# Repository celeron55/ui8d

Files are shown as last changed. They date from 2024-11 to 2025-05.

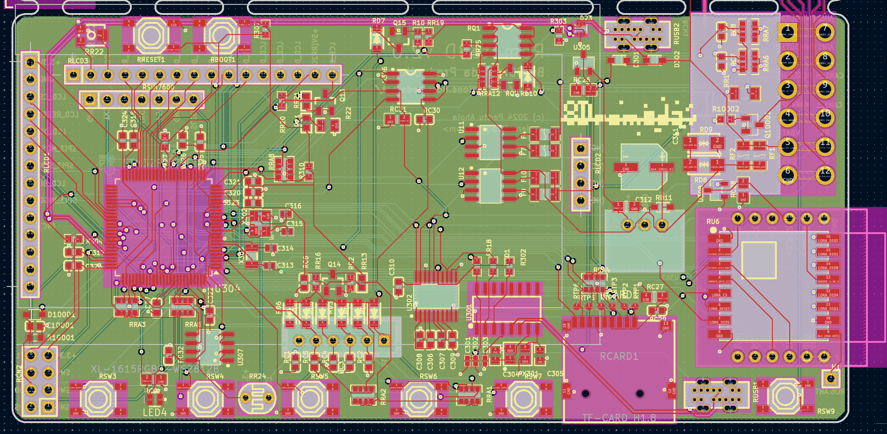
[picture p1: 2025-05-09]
ui8dhw2.0/ui8dhw2.0_pcb_layers.png

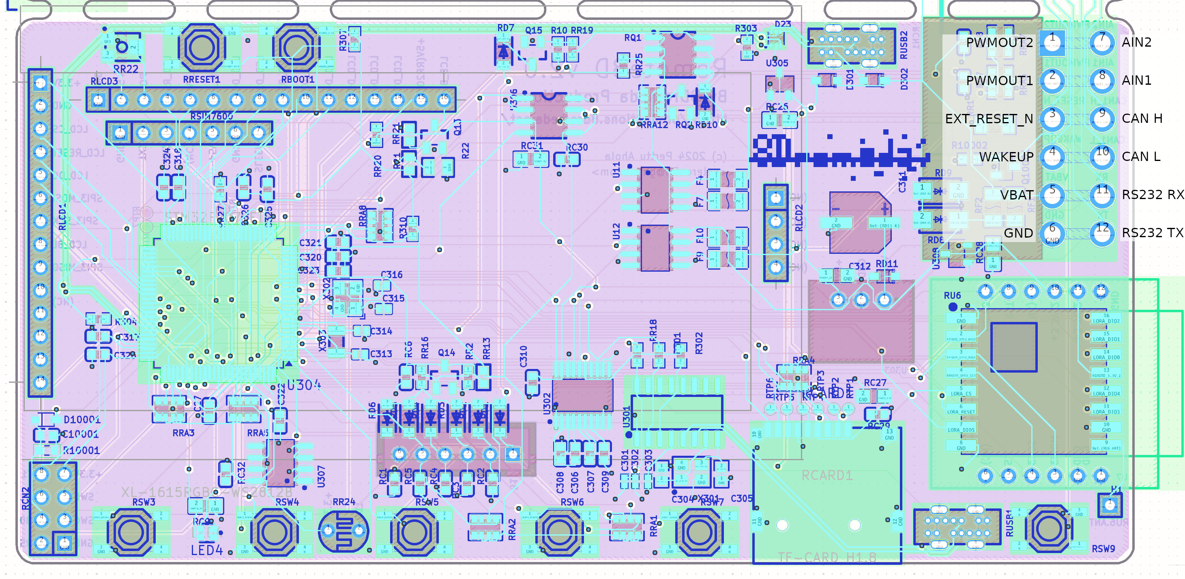
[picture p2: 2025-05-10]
ui8dhw2.0/ui8dhw2.0_connector.png

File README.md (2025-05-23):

UI8D
====

UI8D (ui8d) is a user interface and telematics board. It is mainly targeted
towards EV conversions and for being a companion board to the IPDM56v2, but it
can be useful for other purposes also.

The software runs on an STM32F4 and it can host different modules:
- ILI9341 (LCD)
- SIM7600 (LTE)
- RFM95 (LoRa)
- W5500 (Ethernet)

It can be programmed in multiple programming languages, including:
- Rust
- MicroPython
- C++ (*)
- C (*)

(*) No example software provided

Hardware gotchas
================

UI8D v2.0 (also known as Remote8D v2.0)
---------------------------------------

1. U305 needs to be rotated so that (when looking at it so that there's one top
   pin and two bottom pins) the top pin moves in place of the right pin, and the
   right pin moves in place of the top pin. The remaining pin that was
   originally on the left has to be connected using a bodge wire to ground,
   which can be the original pad of the left pin, or the bottom end of R303.

2. U308 needs to be rotated so that (when looking at it so that there's one top
   pin and two bottom pins) the right pin moves in place of the top pin, the
   left pin remains in place and the top pin has to be connected to the original
   pad of the right pin by a bodge wire.

3. Remember to solder on U303 which is the 5V regulator module. Otherwise the
   board will do nothing.

4. If you have a board where U302 was replaced with SP3223E (it should be an
   SP3222E): In order to use the RS232 connection towards the main board, you
   need to connect U302 pin 14 (ONLINE#) to C310 positive side.
	* In order to check whether the U302 charge pump is working, measure from
	  GND to C308 bottom side (5.7V) and C309 top side (-5.7V), and the TX pin
	  towards the main board should idle at -5.7V.

5. MicroPython on STM32F4 has very little program space in the flash. You may
   want to format a Micro SD card with the fat32 filesystem and insert it into
   the slot. This way you will have practically infinite program space and will
   run out of RAM first. The SD card storage is visible via USB.
	* E.g. `sudo mkfs.fat -F 32 /dev/mmcblk0p1`

6. When pressing BUTTON1 on a bare board, beware of the reset pin on the pin
   header at the corner. You are very likely to accidentally reset the board
   when touching the corner.

7. The PWMOUT1 and PWMOUT2 outputs are driven by EG3001 MOSFET gate drivers that
   will fail if the output is loaded with anything more than a capactive load of
   1nF or so, i.e. they are signal outputs only. If you want to use them _at
   all_, you should replace the 200mA PPTCs with 1k 1206 resistors. This is
   _untested_ and may or may not provide enough protection for the drivers.

Rust example
============

Rust is the recommended programming language, as it allows you to cram way more,
way faster code onto the STM32.

See https://github.com/celeron55/ui8d/tree/master/rust/ui8drust

MicroPython port
================

The MicroPython port for this board is available at
https://github.com/celeron55/ui8d_micropython.git

You can use micropython on UI8D.

You should compile the special board port that was made for the UI8D.

Some modules have been frozen into the firmware, to enable having space left for
the actual program. Here is the current list:
- ili9341.py

Micropython's stm32f407 discovery firmware kind of works, but it has unnecessary
and annoying restrictions like SPI3 and PB3 not being available (needed for the
LCD). 

Compiling:
$ git clone https://github.com/celeron55/ui8d_micropython.git
$ cd ui8d_micropython/ports/stm32
$ vim boards/STM32F407_UI8DV20/mpconfigboard.h
$ make -j6 BOARD=STM32F407_UI8DV20
$ dfu-util -D build-STM32F407_UI8DV20/firmware.dfu

Plug in an SD card into the slot on the Remote8D board. The board will run code
from the SD card, and when plugged into USB, the board will display the SD card
contents instead of interna flash. This allows fitting much more code and
resources for your program and you can update the program outside of the car, by
taking the SD card with you. It will also work as an anti-theft device...

NOTE: Use mpremote to manage the board, OR picocom --baud 115200 -l -e x /dev/ttyACM0

NOTE: Install packages by copying them from https://github.com/micropython/micropython-lib/tree/master/micropython

NOTE: Test programs are located in https://github.com/celeron55/ui8d/tree/master/micropython/examples

```
print("Hello World!")

import machine
from machine import Pin

lcd_backlight = Pin.board.PD12

import neopixel
np = neopixel.NeoPixel(Pin.board.PA6, 1)
np[0] = (4, 0, 0)
np.write()

from pyb import CAN
can = CAN(1, CAN.LOOPBACK)
can.setfilter(0, CAN.LIST16, 0, (123, 124, 125, 126))  
can.send('message!', 123)
can.recv(0)

np[0] = (0, 1, 3)
np.write()

np[0] = (0, 3, 1)
np.write()

while True:
    lcd_backlight.on()
```

License
=======

See LICENSE.txt

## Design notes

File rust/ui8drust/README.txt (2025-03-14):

ui8drust
========

Preparation before doing anything else
--------------------------------------
Set the environment variable BASE_URL:
$ export BASE_URL="http://example.com/report?id=test&"

Symlink your application crate:
$ ln -s /wherever/app app

Or if you don't have a specific application, symlink the example app:
$ ln -s app_example app

Performance benchmarking
------------------------
Heap profiling
- Mainly just to see that Piston is behaving. Heap allocations aren't used on
  the embedded target.
$ cd desktop
$ cargo build
$ valgrind --tool=massif ../target/debug/desktop
$ ms_print massif.out.<pid> | less

Stack profiling:
- This gives an idea about how much memory will be used on the embedded target
  also.
$ cd desktop
$ cargo build
$ valgrind --tool=massif --heap=no --stacks=yes ../target/debug/desktop
$ ms_print massif.out.<pid> | less

Compiling for physical hardware
-------------------------------
$ cd embedded
$ ./build_release.sh

Flashing physical hardware
--------------------------
USB firmware update using automatic DFU mode:
- Connect USB
$ ./flash_dfu_release.sh /dev/ttyACM0

USB firmware update using manual DFU mode:
- Connect USB
- Hold BOOT button
- Click RESET button
- Release BOOT button
- The board should appear as "Product: STM32 BOOTLOADER"
$ ./flash_dfu_release.sh
- OR
$ dfu-util -a 0 --dfuse-address 0x08000000  -D ../target/thumbv7em-none-eabihf/release/embedded.bin

Using an ST-Link v2 clone or similar:
- Connect GND, SWDIO, SWCLK and 3.3V
$ ./flash_openocd_release.sh

- This also kind of works, but RTT logging is not set up so it will complain after flashing succeeds:
$ cargo run --release

Monitoring using USB serial
---------------------------
Pressing a key after running the command starts USB logging
$ picocom --baud 115200 -r -l -c -e x /dev/ttyACM0
$ while true; do picocom --baud 115200 -r -l -c -e x /dev/ttyACM0; sleep 1; done

Debugging on physical hardware
------------------------------
$ cd embedded
$ ./build_release.sh
$ ./flash_openocd_release.sh
$ openocd -f interface/stlink.cfg -f target/stm32f4x.cfg

In another terminal:
$ cd embedded
$ arm-none-eabi-gdb ../target/thumbv7em-none-eabihf/release/embedded
(gdb) target extended-remote localhost:3333
(gdb) break Reset

Editing
-------
- Use any editor (vim is of course recommended 8-))
- Install bacon and run it in another terminal
$ cargo install --locked bacon
$ bacon

Logging
-------
$ picocom --baud 115200 -r -l -c -e x /dev/ttyACM0 | ts %H:%M:%.S
$ picocom --baud 115200 -r -l -c -e x /dev/ttyACM0 | tee $(date +%Y-%m-%d_%H%M%S).log
$ picocom --baud 115200 -r -l -c -e x /dev/ttyUSB0 | ts %H:%M:%.S
$ picocom --baud 115200 -r -l -c -e x /dev/ttyUSB0 | tee $(date +%Y-%m-%d_%H%M%S).log

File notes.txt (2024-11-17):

UI8D
====

UI8D (ui8d) is a user interface and telematics board. It is mainly targeted
towards EV conversions and for being a companion board to the IPDM56v2, but it
can be useful for other purposes also.

MicroPython
-----------
You can use micropython on UI8D.

You should compile the special board port that was made for the UI8D.

Micropython's stm32f407 discovery firmware kind of works, but it has unnecessary
and annoying restrictions like SPI3 and PB3 not being available (needed for the
LCD). 

Compiling:
$ git clone https://github.com/celeron55/ui8d_micropython.git
$ cd ui8d_micropython/ports/stm32
$ vim boards/STM32F407_UI8DV20/mpconfigboard.h
$ make -j6 BOARD=STM32F407_UI8DV20
$ dfu-util -D build-STM32F407_UI8DV20/firmware.dfu

Plug in an SD card into the slot on the Remote8D board. The board will run code
from the SD card, and when plugged into USB, the board will display the SD card
contents instead of interna flash. This allows fitting much more code and
resources for your program and you can update the program outside of the car, by
taking the SD card with you. It will also work as an anti-theft device...

NOTE: Use mpremote to manage the board, OR picocom --baud 115200 -l -e x /dev/ttyACM0

NOTE: Install packages by copying them from https://github.com/micropython/micropython-lib/tree/master/micropython

NOTE: Test programs are located in the ui8d repository, under test_firmware/.

print("Hello World!")

import machine
from machine import Pin

# TODO: PWM control for backlight
# TODO: Measure ambient brightness using LDR at pin PA3 and set brightness based on that
lcd_backlight = Pin.board.PD12

import neopixel
np = neopixel.NeoPixel(Pin.board.PA6, 1)
np[0] = (4, 0, 0)
np.write()

from pyb import CAN
can = CAN(1, CAN.LOOPBACK)
can.setfilter(0, CAN.LIST16, 0, (123, 124, 125, 126))  
can.send('message!', 123)
can.recv(0)

np[0] = (0, 1, 3)
np.write()

#import demo_color_palette
#lcd_backlight.on()
#demo_color_palette.test_palette()

np[0] = (0, 3, 1)
np.write()

while True:
    lcd_backlight.on()

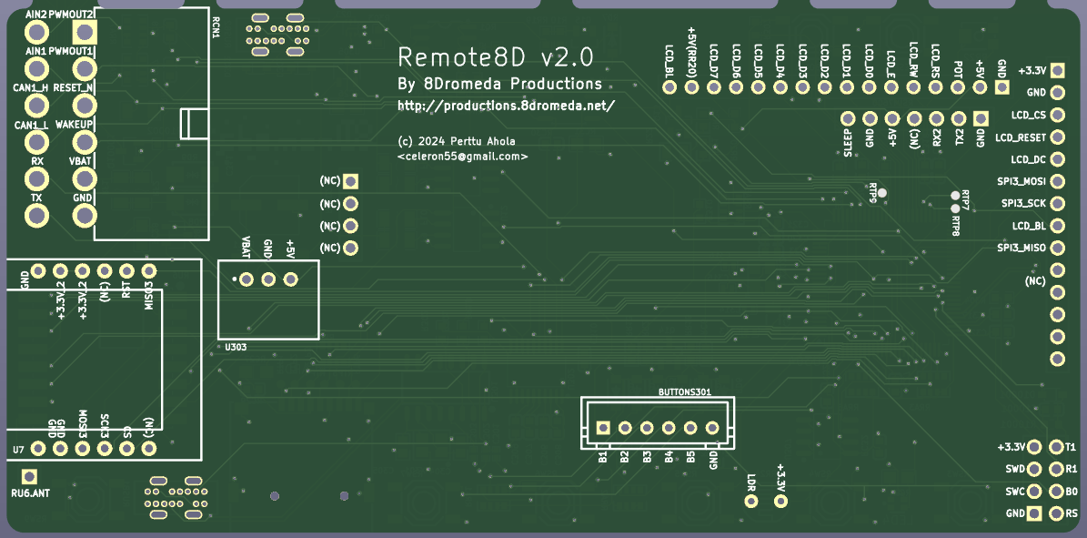
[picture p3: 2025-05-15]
ui8dhw2.0/ui8dhw2.0_pcb_render_back.png

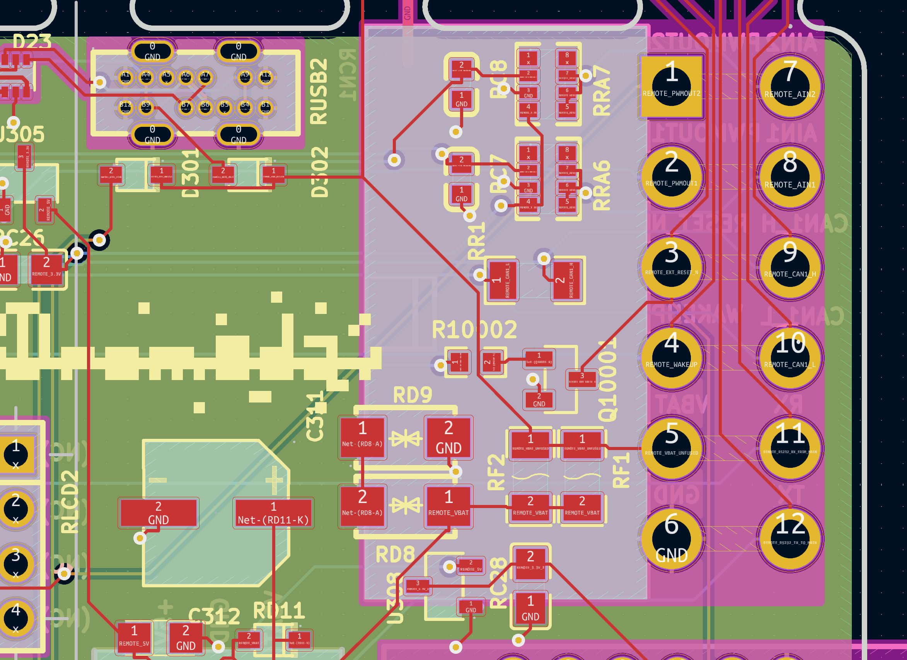
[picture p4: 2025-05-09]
ui8dhw2.0/ui8dhw2.0_pcb_connector.png

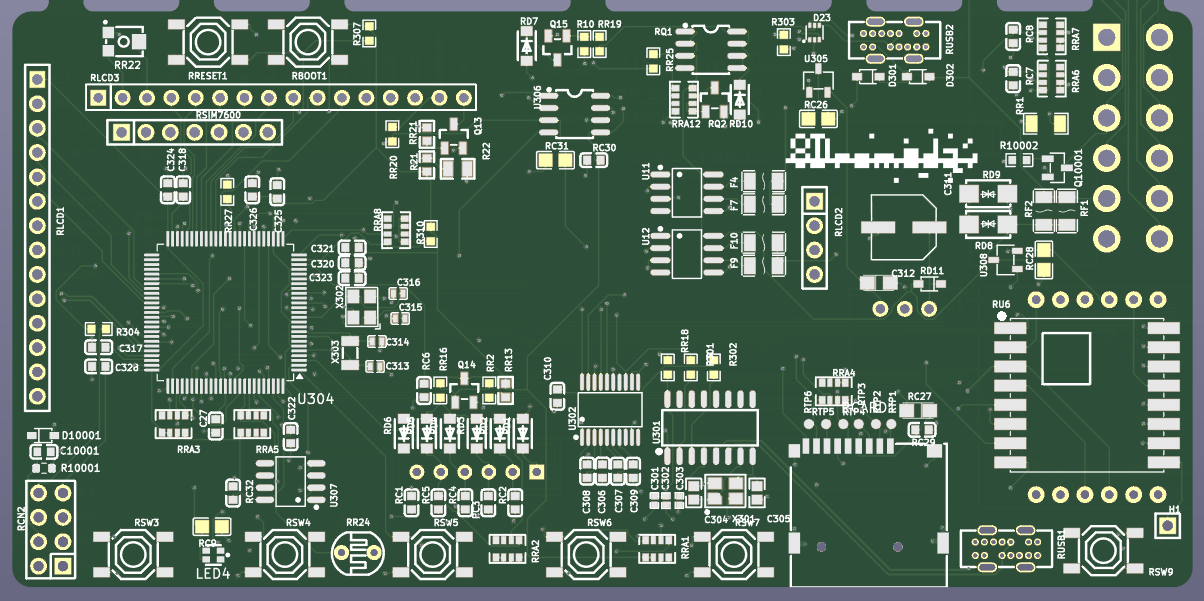
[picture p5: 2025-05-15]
ui8dhw2.0/ui8dhw2.0_pcb_render_front.png

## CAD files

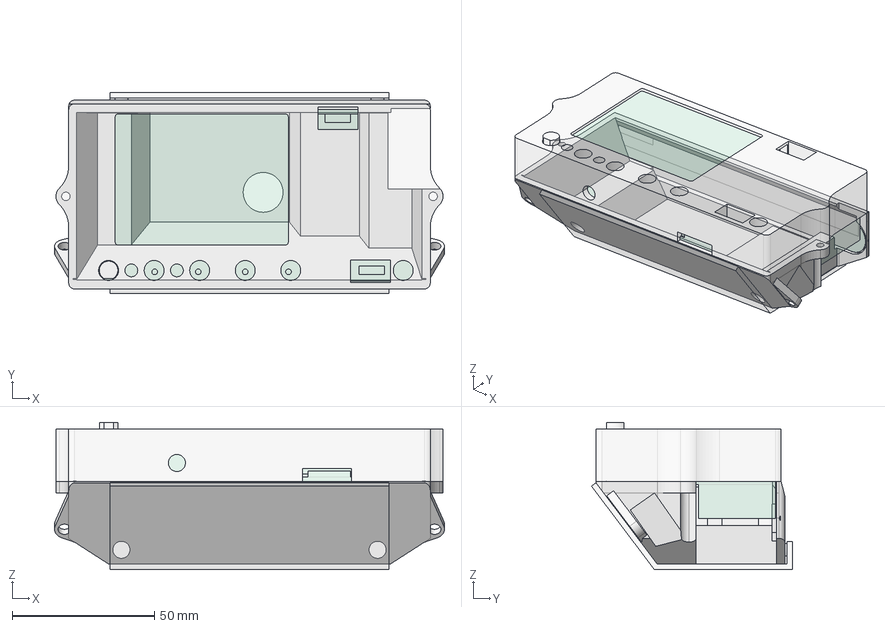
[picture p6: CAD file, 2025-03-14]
enclosure/ui8d_2.0_enclosure1.FCStd
137.0 x 70.6 x 51.8 mm
Main PCB
Riser PCB
LTE PCB
Enclosure front
Enclosure back
Button riser
LTE PCB support block
Antenna
Snap Mount

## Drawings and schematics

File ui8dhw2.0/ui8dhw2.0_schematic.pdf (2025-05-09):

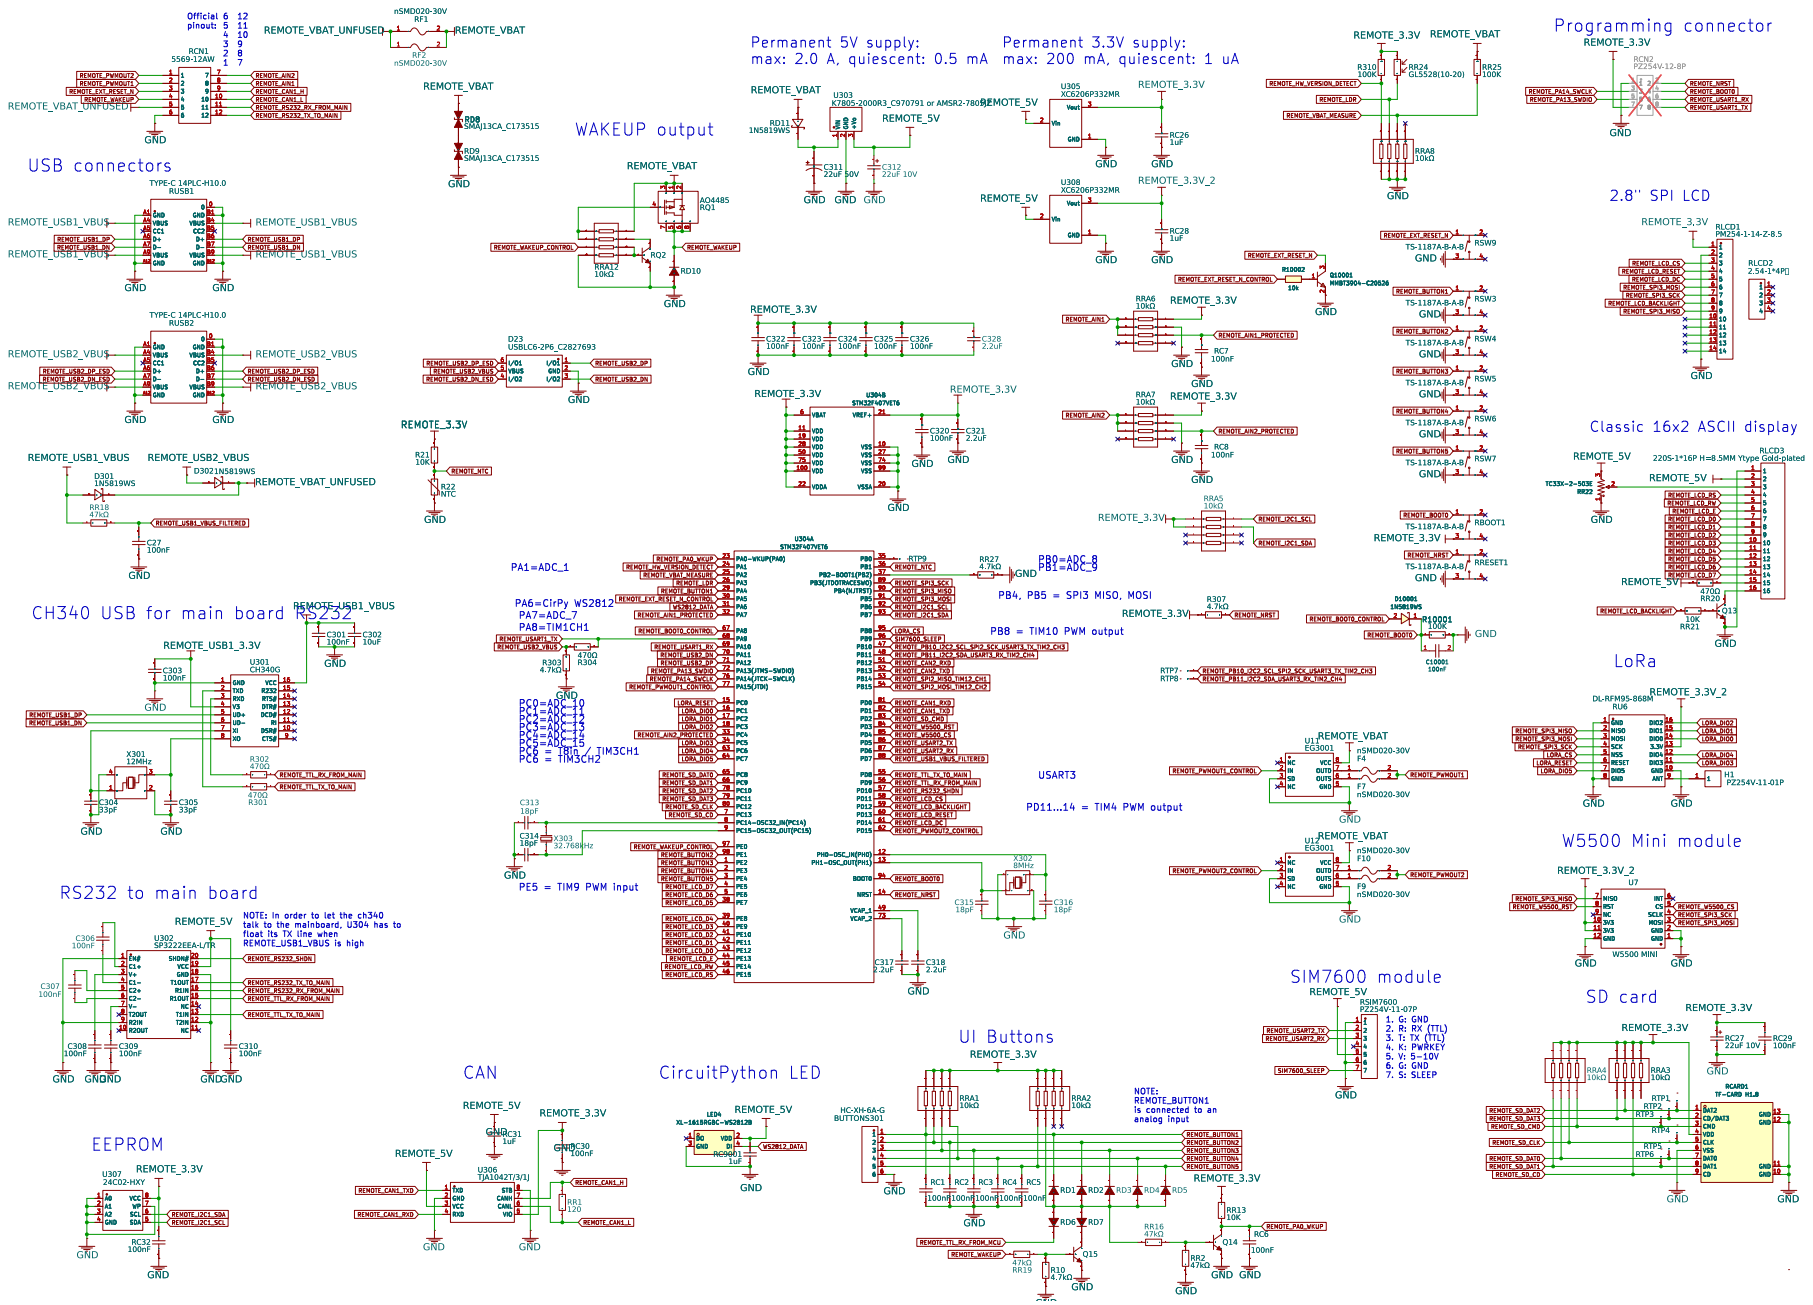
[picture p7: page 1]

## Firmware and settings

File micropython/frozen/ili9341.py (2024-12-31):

"""ILI9341 LCD/Touch module."""
from time import sleep
from math import cos, sin, pi, radians
from sys import implementation
from framebuf import FrameBuffer, RGB565  # type: ignore
from micropython import const  # type: ignore


def color565(r, g, b):
    """Return RGB565 color value.

    Args:
        r (int): Red value.
        g (int): Green value.
        b (int): Blue value.
    """
    return (r & 0xf8) << 8 | (g & 0xfc) << 3 | b >> 3


class Display(object):
    """Serial interface for 16-bit color (5-6-5 RGB) IL9341 display.

    Note:  All coordinates are zero based.
    """

    # Command constants from ILI9341 datasheet
    NOP = const(0x00)  # No-op
    SWRESET = const(0x01)  # Software reset
    RDDID = const(0x04)  # Read display ID info
    RDDST = const(0x09)  # Read display status
    SLPIN = const(0x10)  # Enter sleep mode
    SLPOUT = const(0x11)  # Exit sleep mode
    PTLON = const(0x12)  # Partial mode on
    NORON = const(0x13)  # Normal display mode on
    RDMODE = const(0x0A)  # Read display power mode
    RDMADCTL = const(0x0B)  # Read display MADCTL
    RDPIXFMT = const(0x0C)  # Read display pixel format
    RDIMGFMT = const(0x0D)  # Read display image format
    RDSELFDIAG = const(0x0F)  # Read display self-diagnostic
    INVOFF = const(0x20)  # Display inversion off
    INVON = const(0x21)  # Display inversion on
    GAMMASET = const(0x26)  # Gamma set
    DISPLAY_OFF = const(0x28)  # Display off
    DISPLAY_ON = const(0x29)  # Display on
    SET_COLUMN = const(0x2A)  # Column address set
    SET_PAGE = const(0x2B)  # Page address set
    WRITE_RAM = const(0x2C)  # Memory write
    READ_RAM = const(0x2E)  # Memory read
    PTLAR = const(0x30)  # Partial area
    VSCRDEF = const(0x33)  # Vertical scrolling definition
    MADCTL = const(0x36)  # Memory access control
    VSCRSADD = const(0x37)  # Vertical scrolling start address
    PIXFMT = const(0x3A)  # COLMOD: Pixel format set
    WRITE_DISPLAY_BRIGHTNESS = const(0x51)  # Brightness hardware dependent!
    READ_DISPLAY_BRIGHTNESS = const(0x52)
    WRITE_CTRL_DISPLAY = const(0x53)
    READ_CTRL_DISPLAY = const(0x54)
    WRITE_CABC = const(0x55)  # Write Content Adaptive Brightness Control
    READ_CABC = const(0x56)  # Read Content Adaptive Brightness Control
    WRITE_CABC_MINIMUM = const(0x5E)  # Write CABC Minimum Brightness
    READ_CABC_MINIMUM = const(0x5F)  # Read CABC Minimum Brightness
    FRMCTR1 = const(0xB1)  # Frame rate control (In normal mode/full colors)
    FRMCTR2 = const(0xB2)  # Frame rate control (In idle mode/8 colors)
    FRMCTR3 = const(0xB3)  # Frame rate control (In partial mode/full colors)
    INVCTR = const(0xB4)  # Display inversion control
    DFUNCTR = const(0xB6)  # Display function control
    PWCTR1 = const(0xC0)  # Power control 1
    PWCTR2 = const(0xC1)  # Power control 2
    PWCTRA = const(0xCB)  # Power control A
    PWCTRB = const(0xCF)  # Power control B
    VMCTR1 = const(0xC5)  # VCOM control 1
    VMCTR2 = const(0xC7)  # VCOM control 2
    RDID1 = const(0xDA)  # Read ID 1
    RDID2 = const(0xDB)  # Read ID 2
    RDID3 = const(0xDC)  # Read ID 3
    RDID4 = const(0xDD)  # Read ID 4
    GMCTRP1 = const(0xE0)  # Positive gamma correction
    GMCTRN1 = const(0xE1)  # Negative gamma correction
    DTCA = const(0xE8)  # Driver timing control A
    DTCB = const(0xEA)  # Driver timing control B
    POSC = const(0xED)  # Power on sequence control
    ENABLE3G = const(0xF2)  # Enable 3 gamma control
    PUMPRC = const(0xF7)  # Pump ratio control

    MIRROR_ROTATE = {  # MADCTL configurations for rotation and mirroring
        (False, 0): 0x80,  # 1000 0000
        (False, 90): 0xE0,  # 1110 0000
        (False, 180): 0x40,  # 0100 0000
        (False, 270): 0x20,  # 0010 0000
        (True, 0): 0xC0,   # 1100 0000
        (True, 90): 0x60,  # 0110 0000
        (True, 180): 0x00,  # 0000 0000
        (True, 270): 0xA0  # 1010 0000
    }

    def __init__(self, spi, cs, dc, rst, width=240, height=320, rotation=0,
                 mirror=False, bgr=True, gamma=True):
        """Initialize OLED.

        Args:
            spi (Class Spi):  SPI interface for OLED
            cs (Class Pin):  Chip select pin
            dc (Class Pin):  Data/Command pin
            rst (Class Pin):  Reset pin
            width (Optional int): Screen width (default 240)
            height (Optional int): Screen height (default 320)
            rotation (Optional int): Rotation must be 0 default, 90. 180 or 270
            mirror (Optional bool): Mirror display (default False)
            bgr (Optional bool): Swaps red and blue colors (default True)
            gamma (Optional bool): Custom gamma correction (default True)
        """
        self.spi = spi
        self.cs = cs
        self.dc = dc
        self.rst = rst
        self.width = width
        self.height = height
        if (mirror, rotation) not in self.MIRROR_ROTATE:
            raise ValueError('Rotation must be 0, 90, 180 or 270.')
        else:
            self.rotation = self.MIRROR_ROTATE[mirror, rotation]
            if bgr:  # Set BGR bit
                self.rotation |= 0b00001000
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

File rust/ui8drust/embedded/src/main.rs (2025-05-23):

#![no_std]
#![no_main]
#![feature(type_alias_impl_trait)]

// Local modules

// Internal crates
use command_accumulator::CommandAccumulator;
use common::*;

// Platform-specific dependencies
use adc::{config::AdcConfig, Adc};
use critical_section::Mutex;
use hal::{
    adc::{self, config::SampleTime},
    gpio,
    gpio::PinExt,
    otg_fs, pac,
    prelude::*,
    serial,
};
use rtic_monotonics::{systick::*, Monotonic};
use stm32f4xx_hal as hal;
use usb_device::prelude::*;
use usbd_serial::{self, USB_CLASS_CDC};
// use eeprom24x::Eeprom24x;
use display_interface_spi::SPIInterface;
use embedded_hal_bus;
use ili9341::Ili9341;

// Standard library utilities
use core::{cell::RefCell, fmt::Write, ops::DerefMut};

// General purpose libraries
use arrayvec::{ArrayString, ArrayVec};
use embedded_graphics as eg;
use embedded_graphics::{
    draw_target::DrawTarget, mono_font, pixelcolor::*, prelude::Point, prelude::RgbColor,
    text::Text, Drawable,
};
use fixedstr::str_format;
use log::{debug, error, info, trace, warn, Log, Metadata, Record};
use micromath::F32Ext;
use ringbuffer::{ConstGenericRingBuffer, RingBuffer};

// Constants

const LOG_BUFFER_SIZE: usize = 1024;
const CONSOLE_RX_BUF_SIZE: usize = 100;
const MAINBOARD_RX_BUF_SIZE: usize = 200;
const MAINBOARD_TX_BUF_SIZE: usize = 200;
const SIM7600_RX_BUF_SIZE: usize = 500;
const SIM7600_TX_BUF_SIZE: usize = 500;
const CAN_ENABLE_LOOPBACK_MODE: bool = false;

// Log buffering system

struct MultiLogger {
    uart_buffer: Mutex<RefCell<Option<ArrayString<LOG_BUFFER_SIZE>>>>,
    usb_buffer: Mutex<RefCell<Option<ArrayString<LOG_BUFFER_SIZE>>>>,
    display_buffer: Mutex<RefCell<Option<ArrayString<LOG_BUFFER_SIZE>>>>,
}

impl MultiLogger {
    fn get_uart_buffer(&self) -> Option<ArrayString<LOG_BUFFER_SIZE>> {
        let mut buf2: Option<ArrayString<LOG_BUFFER_SIZE>> = Some(ArrayString::new());
        critical_section::with(|cs| {
            // This replaces the logger buffer with an empty one, and we get the
            // possibly filled in one
            buf2 = self.uart_buffer.borrow(cs).replace(buf2);
        });
        buf2
    }
    fn get_usb_buffer(&self) -> Option<ArrayString<LOG_BUFFER_SIZE>> {
        let mut buf2: Option<ArrayString<LOG_BUFFER_SIZE>> = Some(ArrayString::new());
        critical_section::with(|cs| {
            // This replaces the logger buffer with an empty one, and we get the
            // possibly filled in one
            buf2 = self.usb_buffer.borrow(cs).replace(buf2);
        });
        buf2
    }
    fn get_display_buffer(&self) -> Option<ArrayString<LOG_BUFFER_SIZE>> {
        let mut buf2: Option<ArrayString<LOG_BUFFER_SIZE>> = Some(ArrayString::new());
        critical_section::with(|cs| {
            // This replaces the logger buffer with an empty one, and we get the
            // possibly filled in one
            buf2 = self.display_buffer.borrow(cs).replace(buf2);
        });
        buf2
    }
}

impl Log for MultiLogger {
    fn enabled(&self, metadata: &Metadata) -> bool {
        metadata.level() <= log::Level::Info // TODO: Adjust as needed
    }

    fn log(&self, record: &Record) {
        if self.enabled(record.metadata()) {
            critical_section::with(|cs| {
                if let Some(ref mut buffer) = self.uart_buffer.borrow(cs).borrow_mut().deref_mut() {
                    let _ = buffer.write_fmt(format_args!(
                        "[{}] {}\r\n",
                        record.level(),
                        record.args()
                    ));
                    if buffer.is_full() {
                        let warning = " | LOG BUFFER FULL\r\n";
                        buffer.truncate(buffer.capacity() - warning.len());
                        let _ = buffer.try_push_str(warning);
                    }
                }
                if let Some(ref mut buffer) = self.usb_buffer.borrow(cs).borrow_mut().deref_mut() {
                    let _ = buffer.write_fmt(format_args!(
                        "[{}] {}\r\n",
                        record.level(),
                        record.args()
                    ));
                    if buffer.is_full() {
                        let warning = " | LOG BUFFER FULL\r\n";
                        buffer.truncate(buffer.capacity() - warning.len());
                        let _ = buffer.try_push_str(warning);
                    }
                }
                if let Some(ref mut buffer) =
                    self.display_buffer.borrow(cs).borrow_mut().deref_mut()
                {
                    let _ = buffer.write_fmt(format_args!("{}\r\n", record.args()));
                    if buffer.is_full() {
                        let warning = " | LOG BUFFER FULL\r\n";
                        buffer.truncate(buffer.capacity() - warning.len());
                        let _ = buffer.try_push_str(warning);
                    }
                }
            });
            // Trigger write to hardware by triggering USART1 interrupt
            pac::NVIC::pend(pac::Interrupt::USART1);
            // Trigger write to hardware by triggering OTG_FS interrupt
            pac::NVIC::pend(pac::Interrupt::OTG_FS);
        }
    }

    fn flush(&self) {
        // Flushing is handled elsewhere
    }
}

static MULTI_LOGGER: MultiLogger = MultiLogger {
    uart_buffer: Mutex::new(RefCell::new(None)),
    usb_buffer: Mutex::new(RefCell::new(None)),
    display_buffer: Mutex::new(RefCell::new(None)),
};

// Function to initialize the logger
fn init_logger() {
    critical_section::with(|cs| {
        MULTI_LOGGER
            .uart_buffer
            .borrow(cs)
            .replace(Some(ArrayString::new()));
        MULTI_LOGGER
            .usb_buffer
            .borrow(cs)
            .replace(Some(ArrayString::new()));
        MULTI_LOGGER
            .display_buffer
            .borrow(cs)
            .replace(Some(ArrayString::new()));
    });
    log::set_logger(&MULTI_LOGGER).unwrap();
    log::set_max_level(log::LevelFilter::Info); // TODO: Adjust as needed
}

// CAN driver

pub struct CAN1 {
    _private: (),
}
unsafe impl bxcan::Instance for CAN1 {
    const REGISTERS: *mut bxcan::RegisterBlock = 0x4000_6400 as *mut _;
}
unsafe impl bxcan::FilterOwner for CAN1 {
    const NUM_FILTER_BANKS: u8 = 28;
}

// TIM4 PWM: LCD backlight PWM and PWMOUT2

type Tim4Pwm = hal::timer::PwmHz<
    hal::pac::TIM4,
    (
        hal::timer::ChannelBuilder<hal::pac::TIM4, 0, false>,
        hal::timer::ChannelBuilder<hal::pac::TIM4, 3, false>,
    ),
>;

fn set_lcd_backlight(pwm: f32, pwm_timer: &mut Tim4Pwm) {
    pwm_timer.set_duty(
        hal::timer::Channel::C1,
        (pwm_timer.get_max_duty() as f32 * pwm) as u16,
    );
}

fn set_pwmout2(pwm: f32, pwm_timer: &mut Tim4Pwm) {
    pwm_timer.set_duty(
        hal::timer::Channel::C4,
        (pwm_timer.get_max_duty() as f32 * pwm) as u16,
    );
}

// Buttons

type Button1Pin = gpio::Pin<'A', 4, gpio::Input>;
type Button2Pin = gpio::Pin<'E', 1, gpio::Input>;
type Button3Pin = gpio::Pin<'E', 2, gpio::Input>;
type Button4Pin = gpio::Pin<'E', 3, gpio::Input>;
type Button5Pin = gpio::Pin<'E', 4, gpio::Input>;
type WkupPin = gpio::Pin<'A', 0, gpio::Input>;

// HardwareInterface implementation

type Display = Ili9341<
    SPIInterface<
        embedded_hal_bus::spi::CriticalSectionDevice<
            'static,
            stm32f4xx_hal::spi::Spi<pac::SPI3>,
            gpio::PD11<gpio::Output<gpio::PushPull>>,
            embedded_hal_bus::spi::NoDelay,
        >,
        gpio::PD14<gpio::Output<gpio::PushPull>>,
    >,
    gpio::PD13<gpio::Output<gpio::PushPull>>,
>;

type Boot0ControlPin = gpio::Pin<'A', 8, gpio::Output<gpio::PushPull>>;
type WakeupOutputPin = gpio::Pin<'E', 0, gpio::Output<gpio::PushPull>>;
// TODO: Change this into an actual PWM output
type Pwmout1Pin = gpio::Pin<'A', 15, gpio::Output<gpio::PushPull>>;
type Sim7600PowerInhibitPin = gpio::PB9<gpio::Output<gpio::PushPull>>;

type Usb1VbusInputPin = gpio::Pin<'D', 7, gpio::Input>;

struct HardwareImplementation {
    display: &'static mut Display,
    boot0_control_pin: &'static mut Boot0ControlPin,
    wakeup_output_pin: WakeupOutputPin,
    pwmout1_pin: Pwmout1Pin,
    sim7600_power_inhibit_pin: Sim7600PowerInhibitPin,
    sim7600driver: Sim7600Driver,
    can_tx_buf: ConstGenericRingBuffer<bxcan::Frame, 10>,
    adc_result_vbat: f32,
    adc_result_tpcb: f32,
    usb1_vbus_pin: Usb1VbusInputPin,
}

impl HardwareInterface for HardwareImplementation {
    fn millis(&mut self) -> u64 {
        // NOTE: This rolls over at 49.71 days
        Systick::now().duration_since_epoch().to_millis() as u64
    }

    fn display_clear(&mut self, color: Rgb565) {
        self.display.clear(color).unwrap();
    }

    fn display_draw_text(
        &mut self,
        text: &str,
        p: Point,
        style: mono_font::MonoTextStyle<Rgb565>,
        alignment: eg::text::Alignment,
    ) {
        Text::with_alignment(text, p, style, alignment)
            .draw(self.display)
            .unwrap();
    }

    fn reboot(&mut self) {
        cortex_m::peripheral::SCB::sys_reset();
    }

    fn activate_dfu(&mut self) {
        self.boot0_control_pin.set_high();
        long_busywait();
        cortex_m::peripheral::SCB::sys_reset();
    }

    fn http_get_start(&mut self, url: &str) {
        info!("http_get_start(): url: {:?}", url);

        self.sim7600driver.http_get_start(url);
    }

    fn http_get_update(&mut self) -> HttpUpdateStatus {
        self.sim7600driver.http_get_update()
    }

    fn http_get_stop(&mut self) {
        self.sim7600driver.http_get_stop()
    }

    fn send_can(&mut self, frame: bxcan::Frame) {
        //info!("send_can(): {:?}", frame);
        self.can_tx_buf.push(frame);
    }

    fn get_analog_input(&mut self, input: AnalogInput) -> f32 {
        match input {
            AnalogInput::AuxVoltage => self.adc_result_vbat,
            AnalogInput::PcbT => self.adc_result_tpcb,
        }
    }

    fn get_digital_input(&mut self, input: DigitalInput) -> bool {
        match input {
            DigitalInput::Usb1Connected => self.usb1_vbus_pin.is_high(),
        }
    }

    fn set_digital_output(&mut self, output: DigitalOutput, value: bool) {
        // TODO
        match output {
            DigitalOutput::Wakeup => { self.wakeup_output_pin.set_state(value.into()) }
            DigitalOutput::Pwmout1 => { self.pwmout1_pin.set_state(value.into()) }
            DigitalOutput::Sim7600PowerInhibit => { self.sim7600_power_inhibit_pin.set_state(value.into()) }
        }
    }
}

// Panic output and input methods

static mut PANIC_TX: Option<hal::serial::Tx<hal::pac::USART1, u8>> = None;
static mut PANIC_DISPLAY: Option<Display> = None;
static mut PANIC_BOOT0_CONTROL_PIN: Option<Boot0ControlPin> = None;
static mut PANIC_BUTTON1_PIN: Option<Button1Pin> = None;
static mut PANIC_BUTTON3_PIN: Option<Button3Pin> = None;

// RTIC application

#[rtic::app(device = hal::pac, peripherals = true, dispatchers = [UART5, I2C3_ER, USART6])]
mod rtic_app {
    use super::*;

    #[shared]
    struct Shared {
        usb_dev: UsbDevice<'static, otg_fs::UsbBusType>,
        usb_serial: usbd_serial::SerialPort<'static, otg_fs::UsbBusType>,
        console_rxbuf: ConstGenericRingBuffer<u8, CONSOLE_RX_BUF_SIZE>,
        sim7600_rxbuf: ConstGenericRingBuffer<u8, SIM7600_RX_BUF_SIZE>,
        sim7600_txbuf: ConstGenericRingBuffer<u8, SIM7600_TX_BUF_SIZE>,
        mainboard_rxbuf: ConstGenericRingBuffer<u8, MAINBOARD_RX_BUF_SIZE>,
        mainboard_txbuf: ConstGenericRingBuffer<u8, MAINBOARD_TX_BUF_SIZE>,
        can1: bxcan::Can<CAN1>,
        can_rx_buf: ConstGenericRingBuffer<bxcan::Frame, 50>,
        can_tx_buf: ConstGenericRingBuffer<bxcan::Frame, 10>,
        button1_pin: &'static mut Button1Pin,
        button2_pin: Button2Pin,
        button3_pin: &'static mut Button3Pin,
        button4_pin: Button4Pin,
        button5_pin: Button5Pin,
        wkup_pin: WkupPin, // The WKUP input pin
        button_event_queue: ConstGenericRingBuffer<ButtonEvent, 10>,
        adc_result_ldr: u16,
        adc_result_vbat: f32,
        adc_result_tpcb: f32,
    }

    #[local]
    struct Local {
        usart1_rx: hal::serial::Rx<hal::pac::USART1, u8>,
        usart1_tx: &'static mut hal::serial::Tx<hal::pac::USART1, u8>,
        usart2_rx: hal::serial::Rx<hal::pac::USART2, u8>,
        usart2_tx: hal::serial::Tx<hal::pac::USART2, u8>,
        usart3_rx: hal::serial::Rx<hal::pac::USART3, u8>,
        //usart3_tx: hal::serial::Tx<hal::pac::USART3, u8>,
        command_accumulator: CommandAccumulator<50>,
        i2c1: hal::i2c::I2c<hal::pac::I2C1>,
        adc1: Adc<pac::ADC1>,
        // Analog input pins
        adc_pa1: gpio::Pin<'A', 1, gpio::Analog>,
        adc_pa2: gpio::Pin<'A', 2, gpio::Analog>,
        adc_pa3: gpio::Pin<'A', 3, gpio::Analog>,
        adc_pb1: gpio::Pin<'B', 1, gpio::Analog>,
        // Digital input pins
        // Output pins
        // (See HardwareImplementation)
        // PWM output timers
        tim4_pwm: Tim4Pwm,
        last_backlight_pwm: f32,
        // Other
        hw: HardwareImplementation,
    }

    #[init()]
    fn init(mut cx: init::Context) -> (Shared, Local) {
        static mut EP_MEMORY: [u32; 1024] = [0; 1024];
        static mut USB_BUS: Option<usb_device::bus::UsbBusAllocator<otg_fs::UsbBusType>> = None;
        static mut SPI3_SHARED: Option<Mutex<RefCell<hal::spi::Spi<hal::pac::SPI3>>>> = None;

        // System clock

        // Enable CAN1
        cx.device.RCC.apb1enr.modify(|_, w| w.can1en().enabled());

        let rcc = cx.device.RCC.constrain();
        let clocks = rcc
            .cfgr
            .use_hse(8.MHz()) // Use external crystal (HSE)
            .hclk(168.MHz())
            .pclk1(42.MHz())
            .pclk2(84.MHz())
            .sysclk(168.MHz()) // Set system clock (SYSCLK)
            .freeze(); // Apply the configuration

        let mut syscfg = cx.device.SYSCFG.constrain();

        // Pin assignments

        let gpioa = cx.device.GPIOA.split();
        let gpiob = cx.device.GPIOB.split();
        let gpioc = cx.device.GPIOC.split();
        let gpiod = cx.device.GPIOD.split();
        let gpioe = cx.device.GPIOE.split();

        // Input pins

        let mut usb1_vbus_pin = gpiod.pd7.into_input();

        // Output pins

        let sim7600_power_inhibit_pin = gpiob
            .pb9
            .into_push_pull_output_in_state(gpio::PinState::Low);

        let boot0_control_pin = gpioa.pa8.into_push_pull_output();
        let boot0_control_pin = unsafe {
            PANIC_BOOT0_CONTROL_PIN = Some(boot0_control_pin);
            PANIC_BOOT0_CONTROL_PIN.as_mut().unwrap()
        };

        let mut wakeup_output_pin = gpioe.pe0.into_push_pull_output();
        let mut pwmout1_pin = gpioa.pa15.into_push_pull_output();

        // External interrupt pins

        // NOTE: button1 and button5 both use EXTI4. On stm32f4, it's not
        // possible to have two pins be the source of the same external
        // interrupt. Thus, we use the PA0(WKUP) pin to detect button1 presses,
        // as it is wired to go high every time a button is pressed and it can
        // act as EXTI0 source.
        let mut button1_pin = gpioa.pa4.into_pull_up_input();
        //button1_pin.make_interrupt_source(&mut syscfg);
        //button1_pin.enable_interrupt(&mut cx.device.EXTI);
        //button1_pin.trigger_on_edge(&mut cx.device.EXTI, gpio::Edge::Falling);
        let button1_pin = unsafe {
            PANIC_BUTTON1_PIN = Some(button1_pin);
            PANIC_BUTTON1_PIN.as_mut().unwrap()
        };
        let mut wkup_pin = gpioa.pa0.into_input();
        wkup_pin.make_interrupt_source(&mut syscfg);
        wkup_pin.enable_interrupt(&mut cx.device.EXTI);
        wkup_pin.trigger_on_edge(&mut cx.device.EXTI, gpio::Edge::RisingFalling);

        let mut button2_pin = gpioe.pe1.into_pull_up_input();
        button2_pin.make_interrupt_source(&mut syscfg);
        button2_pin.enable_interrupt(&mut cx.device.EXTI);
        button2_pin.trigger_on_edge(&mut cx.device.EXTI, gpio::Edge::Falling);

        let mut button3_pin = gpioe.pe2.into_pull_up_input();
        let button3_pin = unsafe {
            PANIC_BUTTON3_PIN = Some(button3_pin);
            PANIC_BUTTON3_PIN.as_mut().unwrap()
        };
        button3_pin.make_interrupt_source(&mut syscfg);
        button3_pin.enable_interrupt(&mut cx.device.EXTI);
        button3_pin.trigger_on_edge(&mut cx.device.EXTI, gpio::Edge::Falling);

        let mut button4_pin = gpioe.pe3.into_pull_up_input();
        button4_pin.make_interrupt_source(&mut syscfg);
        button4_pin.enable_interrupt(&mut cx.device.EXTI);
        button4_pin.trigger_on_edge(&mut cx.device.EXTI, gpio::Edge::Falling);

        let mut button5_pin = gpioe.pe4.into_pull_up_input();
        button5_pin.make_interrupt_source(&mut syscfg);
        button5_pin.enable_interrupt(&mut cx.device.EXTI);
        button5_pin.trigger_on_edge(&mut cx.device.EXTI, gpio::Edge::Falling);

        // SysTick

        let systick_token = rtic_monotonics::create_systick_token!();
        Systick::start(cx.core.SYST, 168_000_000, systick_token); // Eats SYST peripheral

        // Software utilities

        init_logger();

        info!("-!- ui8d boot");

        // SPI bus

        // The SPI bus is shared between the SPI LCD and the optional LoRa and
        // W5500 modules

        // The SPI bus is accessed from different interrupts, so we have to use
        // embedded_hal_bus::spi::CriticalSectionDevice. If it was accessed from
        // only a single interrupt, we could use RefCellDevice instead.

        let spi3 = hal::spi::Spi::new(
            cx.device.SPI3,
            (
                gpiob.pb3.into_alternate::<6>(),
                gpiob.pb4.into_alternate::<6>(),
                gpiob.pb5.into_alternate::<6>().internal_pull_up(true),
            ),
            hal::spi::Mode {
                polarity: hal::spi::Polarity::IdleLow,
                phase: hal::spi::Phase::CaptureOnFirstTransition,
            },
            40.MHz(),
            &clocks,
        );

        let spi3_shared = unsafe {
            // The SPI3 bus shared by multiple peripherals is stored here. The
            // static lifetime makes things a lot easier
            SPI3_SHARED = Some(Mutex::new(RefCell::new(spi3)));
            SPI3_SHARED.as_mut().unwrap()
        };

        // LCD backlight and PWMOUT2

        let backlight_ch: hal::timer::ChannelBuilder<hal::pac::TIM4, 0, false> =
            hal::timer::Channel1::new(gpiod.pd12);
        let pwmout_ch: hal::timer::ChannelBuilder<hal::pac::TIM4, 3, false> =
            hal::timer::Channel4::new(gpiod.pd15);

        let mut tim4_pwm = cx
            .device
            .TIM4
            .pwm_hz((backlight_ch, pwmout_ch), 1000.Hz(), &clocks);

        tim4_pwm.enable(hal::timer::Channel::C1);
        tim4_pwm.enable(hal::timer::Channel::C4);
        set_lcd_backlight(0.2, &mut tim4_pwm);
        set_pwmout2(0.20, &mut tim4_pwm);

        // SPI LCD

        let mut lcd_reset_pin = gpiod.pd13.into_push_pull_output();
        let mut lcd_cs_pin = gpiod.pd11.into_push_pull_output();
        let lcd_dc_pin = gpiod.pd14.into_push_pull_output();

        let spi3_lcd =
            embedded_hal_bus::spi::CriticalSectionDevice::new_no_delay(spi3_shared, lcd_cs_pin);

        let spi_iface = SPIInterface::new(spi3_lcd, lcd_dc_pin);

        let mut delay = cx.device.TIM1.delay_us(&clocks);
        let mut display = Ili9341::new(
            spi_iface,
            lcd_reset_pin,
            &mut delay,
            ili9341::Orientation::LandscapeFlipped,
            ili9341::DisplaySize240x320,
        )
        .unwrap();

        let display = unsafe {
            PANIC_DISPLAY = Some(display);
            PANIC_DISPLAY.as_mut().unwrap()
        };

        display.clear(Rgb565::BLACK).unwrap();

        let style =
            mono_font::MonoTextStyle::new(&mono_font::iso_8859_10::FONT_10X20, Rgb565::WHITE);
        Text::with_alignment(
            "ui8d",
            Point::new(319, 24),
            style,
            eg::text::Alignment::Right,
        )
        .draw(display)
        .unwrap();

        // USART1 (TX=PA9, RX=PA10): TTL serial on programming header. We
        // provide our serial console here, and also on native USB. Note that
        // PA9 is also USB VBUS detect, because the bootloader wants that there.

        let serial_usart1: serial::Serial<pac::USART1, u8> = serial::Serial::new(
            cx.device.USART1,
            (
                gpioa.pa9.into_alternate::<7>(),
                gpioa.pa10.into_alternate::<7>(),
            ),
            serial::config::Config::default().baudrate(115200.bps()),
            &clocks,
        )
        .unwrap();
        let (usart1_tx, mut usart1_rx) = serial_usart1.split();
        usart1_rx.listen();
        let usart1_tx = unsafe {
            PANIC_TX = Some(usart1_tx);
            PANIC_TX.as_mut().unwrap()
        };

        // USART2 (TX=PD5, RX=PD6): SIM7600 UART

        let serial_usart2: serial::Serial<pac::USART2, u8> = serial::Serial::new(
            cx.device.USART2,
            (
                gpiod.pd5.into_alternate::<7>(),
                gpiod.pd6.into_alternate::<7>(),
            ),
            serial::config::Config::default().baudrate(115200.bps()),
            &clocks,
        )
        .unwrap();
        let (usart2_tx, mut usart2_rx) = serial_usart2.split();
        usart2_rx.listen();

        // USART3 (TX=PD8, RX=PD9): RS232 to iPDM56v2. These pins should be
        // floated when direct communication to mainboard via USB connector is
        // wanted, e.g.  when flashing the main board or when using the
        // mainboard serial console via USB.
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

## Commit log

2024-12-28 enclosure: Adjust and add place for SD card, mainboard reset button and local reset and boot
    [ui8d_2.0_enclosure1.FCStd]
2024-12-29 enclosure: Button riser
    [ui8d_2.0_enclosure1.FCStd]
2024-12-29 enclosure: Adjust display dimensions to hide white bezel at bottom and right side
    [ui8d_2.0_enclosure1.FCStd]
2024-12-29 enclosure: 6.5mm buttons in 7.0mm holes
    [ui8d_2.0_enclosure1.FCStd]
2024-12-29 enclosure: Back half of enclosure
    [ui8d_2.0_enclosure1.FCStd]
2024-12-29 enclosure: Replace button risers with the ones edited in the garage
    [ui8d_2.0_enclosure1.FCStd]
2024-12-30 enclosure: LTE PCB support block
    [ui8d_2.0_enclosure1.FCStd]
2024-12-31 enclosure: Space for LTE antenna (only back cover is modified)
    [ui8d_2.0_enclosure1.FCStd]
2025-03-14 enclosure: Add snap mount
    [ui8d_2.0_enclosure1.FCStd]
2025-03-14 Move most application specific code into app crate, which by default doesn't exist
    [lib.rs, main.rs]
2025-03-15 ui8drust: Bring in SIM7600 related fixes from downstream project
    [lib.rs, main.rs]
2025-03-16 ui8drust: Bring in SIM7600 related fixes from a downstream project
    [main.rs]
2025-03-23 ui8drust: Bring in fixes from a downstream project
    [lib.rs]
2025-05-09 ui8dhw2.0: Add board layout and connector pinout
2025-05-09 ui8dhw2.0: Add schematic
2025-05-10 ui8drust: Correct I2C SCL pin (PB8 -> PB6)
    [main.rs]
2025-05-12 ui8drust/app_example: Add cruise control button
2025-05-15 ui8dhw2.0: PCB renders
